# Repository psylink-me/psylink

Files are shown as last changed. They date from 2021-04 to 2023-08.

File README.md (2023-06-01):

# PsyLink






Open source [myoelectric](https://en.wikipedia.org/wiki/Electromyography) neural interface.

[Website](https://psylink.me) ::
[Documentation](https://codeberg.org/psylink/psylink/wiki) ::
[Matrix Chatroom](https://matrix.to/#/#psylink:matrix.org) ::
[FAQ](https://psylink.me/faq)

Photograph of PsyLink Prototype 10

# Introduction

**Psylink** is intended as a human input device (like a keyboard) that predicts your
intention from muscle signals.  Using a neural network, trained through a
process where you press keys at the exact same time that you make movements
with the limb wearing the device, it learns correlations between the muscle
signals and intended keys, and can press them for you.

- [Video demos @ PeerTube](https://peertube.linuxrocks.online/video-channels/psylink/videos)
- [Development Log](https://psylink.me/blog)
- [Whats Next?](https://codeberg.org/psylink/psylink/wiki/Next-Steps)

# Software used to create/edit/run these files

- Schematics, PCB Layouts: KiCad 6.0 (some archived ones used 5.1.5)
- Arduino IDE 1.8.19
    - ArduinoBLE 1.2.1
    - Arduino\_LSM9DS1 1.1.0
- Python 3.8
    - For library versions, see the respective requirements.txt file
- GnuRadio 3.8.1.0

# Datasheet

This describes [prototype 4](https://psylink.me/p4).

photo of the device

- Features:
    - Battery-powered
    - Wireless, using Bluetooth Low Energy (BLE)
    - Supports 17 electrodes (8 pairs + 1 ground)
    - Transmits 8 signals at 8-bit resolution, 500Hz sampling rate
    - Linux graphical user interface for:
        - Mapping keyboard key presses to muscle signals
        - Training a neural network to predict key presses from signals
        - Simulating key presses based on neural network predictions
    - GNURadio integration for plotting the raw signals + FFT
- Hardware overview:
    - A fabric glove/sleeve with a central component (arduino + power supply)
      and 8 distributed signal clean-up units close to individual electrodes.
    - [KiCad Schematic](schematics/myocular0.5.1.sch)
    - [KiCad PCB of one distributed signal clean-up unit](schematics/myocular0.5.1d.kicad_pcb)
- Software dependencies:
    - Python3 (see [requirements.txt](python/requirements.txt))
        - [BLE-GATT](https://pypi.org/project/BLE-GATT/)
        - [matplotlib](https://matplotlib.org/)
        - [pynput](https://pypi.org/project/pynput/)
        - [tensorflow](https://www.tensorflow.org/)
        - [Pillow](https://python-pillow.org)
        - possibly the `python3-pil.imagetk` package
    - ArduinoIDE
        - [ArduinoBLE](https://www.arduino.cc/en/Reference/ArduinoBLE)
        - [Arduino LSM9DS1](https://www.arduino.cc/en/Reference/ArduinoLSM9DS1) (for accelerometer/gyroscope)
- Components:
    - 1x [Arduino Nano 33 BLE Sense](https://store.arduino.cc/arduino-nano-33-ble-sense)
    - 1x [LM324 Operational Amplifier](https://www.ti.com/product/LM324)
    - 8x [INA128 Instrumentational Amplifier](https://www.ti.com/product/INA128)
    - Any portable 6V power supply (like 2x CR2032)
    - 17x Electrodes, e.g. [Prym 390120](https://www.prym.com/en/non-sew-refill-for-390120-smooth-cap-10mm-silver-coloured-390104) (don't laugh, they work)
    - A forearm sleeve from non-conductive fabric
    - Additional standard components (see schematic)
- Power ratings
    - Supply Voltage: 4.5-6V
    - Power dissipation:
        - Idle: ~86.9mW (16.9mA x 5.14V)
        - Transmitting at 6-7kB/s: 92.5mW (18.0mA x 5.14V)
- Weight: ~85g (at 9.81m/s² gravitational acceleration)

# Acknowledgements

Very special thanks to every contributor. You all shaped the direction of this
project in your unique way, and we would not be at this point without you!

- [Roman Zimbelmann](https://rzim.dev): Founder and maintainer of PsyLink
- [Alex Lao](http://www.voltagedivide.com/): Consulting
- [AntonX](https://www.linkedin.com/in/anton-x/): Consulting, hardware design
- [Cade Brown](https://cade.site/): Testing, financial support
- [Fabien Devaux](http://github.com/fdev31/): Consulting
- [Farzam Khodajoo](https://www.linkedin.com/in/farzam-khodajoo): Consulting, hardware design
- [Hackaday.com](https://hackaday.com/2022/01/07/psylink-an-open-source-neural-interface-for-non-invasive-emg/): Spreading the word, networking
- [John Shahbazian](https://github.com/jshahbazi): Consulting, testing, software, financial support
- keks: Consulting, testing
- knoc: Consulting, testing
- [ktrask](https://twitter.com/ktrask23) ([mastodon](https://chaos.social/@ktrask)): Consulting, testing
- [PCBWay](https://pcbway.com): Sponsored production services
- [PerlinWarp](https://twitter.com/perlinwarp): Consulting, testing, documentation, networking, financial support
- Ricard Collins: Consulting, financial support, testing
- [Wojciech Siewierski](https://einval.eu): Consulting
- Thanks to all the patrons on [Liberapay](https://liberapay.com/psylink/) for financial support!

# License

Copyright (C) 2023  Roman Zimbelmann

This program is free software: you can redistribute it and/or modify
it under the terms of the GNU General Public License version 3 as
published by the Free Software Foundation.

This program is distributed in the hope that it will be useful,
but WITHOUT ANY WARRANTY; without even the implied warranty of
MERCHANTABILITY or FITNESS FOR A PARTICULAR PURPOSE.  See the
GNU General Public License for more details.

You should have received a copy of the GNU General Public License
along with this program.  If not, see <https://www.gnu.org/licenses/>.

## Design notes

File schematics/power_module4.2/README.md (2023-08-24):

# PsyLink Power Module 4.2

This board connects to a [Arduino Nano 33 BLE](https://docs.arduino.cc/hardware/nano-33-ble) or [BLE Sense](https://docs.arduino.cc/hardware/nano-33-ble-sense) and a AAA battery, with the purpose to power the Arduino and expose a variety of I/O pins and power pins in order to power further boards such as the PsyLink electrode modules.

Though it was designed to drive PsyLink electrode modules, it can also be used stand-alone as a battery-powered break-out board for any Arduino board that is pin-compatible with the [Arduino Nano 33 BLE](https://docs.arduino.cc/hardware/nano-33-ble), for example as a mobile [water detector](https://psylink.me/blog/retro2022/#psylink-as-a-break-out-board):

Photograph of the PsyLink power module 4.2 with a speaker plugged in to D10/D13, and two wires on A0 and GND, above a cup of water. When both wires touch the water, the speaker makes some noise.

# Overview

- Part ID: ["bp4.2"](https://psylink.me/bp4.2/)
- Circuit ID: ["12.1"](https://psylink.me/c12.1/)
- Dimensions: 90 x 32.6mm
- Finalized on: 2022-01-26
- Tested: Yes
- Bill of materials: [LibreOffice .ods file](https://psylink.me/tables/bom_p10.ods)
- Known bugs:
    - Power LED (D1) drains a lot of power. Mitigate this by increasing the resistor (R5) or removing the LED entirely - there is another power LED on the Arduino anyway.

# Main Features

- Provides 5V operating voltage for the Arduino and the rest of the circuit by boosts the battery voltage up to 5V with a [TSP61220](https://www.ti.com/product/de-de/TPS61220) step-up converter
- Supports AAA batteries. Tested with 1.5V non-rechargeable, and 1.2V NiMH rechargeable. Plugged into "Keystone 82" battery clips
- Generates 2.5V Reference Voltage (Vref) with a [LM321](https://www.ti.com/product/LM321) for the ground electrode and to serve as a baseline for the electrode modules
- Exposes Arduino pins A0-A8, D2, D3, D10-D13
- Exposes power output connectors that supply V+, Vref, GND. Three sets of these are available to power 3 electrode modules, but more can be connected via daisy-chaining.
- Features an optional power LED, though I recommend leaving it out to conserve power. The Arduino already provides another power LED.
- Provides mounting points for 5 dome nuts (e.g. [M3 dome nuts of A2 stainless steel](https://www.schraubenking.at/M3-Hutmutter-DIN1587-Edelstahl-A2-P002263)) that act as ground electrode and spacers between the board and the skin, although it is still required to place insulating tape over any exposed metal on the board (other than the screws) to ensure proper function
- Can be worn on a limb by utilizing the rubber band holes on the sides of the PCB.
    -  An isolating tape must fully cover any metal contact points the bottom side
- Supports a 3.3V operating mode by changing the value of R2 from 110kΩ to 180kΩ. This will also change Vref from 2.5V to 1.65V, and if you use a power LED, its resistor R5 may need adjustment.
- You can change the values for R3, R4, and all capacitors by ~1 order of magnitude without too much impact. R3 needs to be equal to R4. R5 may need to be adapted to whichever LED and supply voltage you use, see e.g. [this LED resistor calculator](https://www.allaboutcircuits.com/tools/led-resistor-calculator/).
- Customization via jumpers:
    - JP1: Exposes D2, GND, D3, so you can ground D2 or D3 with a jumper to change the device behavior on the fly
    - JP2: Enable measuring the battery voltage with A7, which sacrifices one electrode signal
    - JP3: Solder jumper to enable the reference voltage generator
    - JP4-JP8: Enables one of the 5 screws/dome-nuts to act as a ground electrode. At least one of them should be activated, and the screw should touch the skin.

# IMPORTANT ASSEMBLY INSTRUCTIONS

- Cover the bottom of the board with isolating tape if it is placed on the skin
- The inductance L1 must be rated for at least 230mA
- Before soldering on any through-hole components, their pins must be shortened with e.g. wire cutters so that they do not extend out of the board on the bottom side, to avoid scratching the skin
- You must close the solder jumpers JP3 and (e.g.) JP4 for proper function
- The screws connect Vref to the skin (if their resp. jumper is closed). You MUST manually connect Vref with the skin if this board is not worn on the skin directly and if you use this board along with the electrode modules for EMG purposes. Keep a distance of at least 3cm with this ground electrode from any other electrode.
- It's more comfortable to wear if you leave out screw 5.

# PCB Images

Front Side

Back Side

# Circuit Image

Circuit

# Changelog

Power Module 4.2:

- Added logo
- Added "OFF" and "ON" labels to power switch
- Simplified power LED circuit: it is now always connected to V+ instead of giving you the choice between V+ and Vref via a jumper
- Moved the external power pins (J7) away from the center of the battery, so the pin headers are not physically in the way when removing the battery.

Power Module 4.1:

- Added pins for external power supply
- Added optional power LED circuit, with a jumper (JP9) that lets you choose between powering it with Vref (should consume less power) or V+ (in case you disable Vref generator via jumper JP3)
- Repositioned some parts

Power Module 4.0:

- Redesigned from scratch to be worn on the arm directly, instead of being attached to a piece of fabric via velcro as before
- Longer but thinner board by repositioning the battery in line with the Arduino rather than side-by-side, so that it fits better on the arm
- Added holes for rubber bands on the sides, compatible with corresponding electrode modules.
- Added screw mounting slots for ground electrodes, connected to Vref. Only one of them needs to be enabled via a jumper (JP4-JP8)
- Power output pins (V+, Vref, GND) for powering electrode modules are now separated from the I/O pins into distinct 3-pin connectors
- Added a third set of power output pins
- New dimensions: 90 x 32.6mm

Power Module 3.1:

- Changed package for L1 inductance coil from 1206 to 1210, so one can fit larger coils with a higher maximum current rating on it
- For easier soldering, added thermal reliefs on the filled area for GND on the back side
- For easier soldering, added larger pads for L1/U*/R*/C* components (see [issue #8](https://codeberg.org/psylink/psylink/issues/8))
- No changes to the circuit

Power Module 3:

- Redesigned PCB from scratch
- Actually works
- Both Arduino and battery clips are now on the top side
- Added bypass capacitors to reduce noise
- Added various jumpers:
    - A solder jumper to enable/disable the reference voltage generator, to save power when it's not needed
    - A solder jumper to sacrifice one electrode and use its analog input pin to measure the battery charge instead.
    - Three configuration pins that expose the Arduino's D2, GND, D3 pins, connectable via jumpers, to change software settings on the fly and toggle between up to 4 different modes. Or you can use them to plug in an extra module.
- New dimensions: 47.63 x 31.34mm

Power Module 2 (defunct):

- Switched from manual wiring to PCB
- Switched from 2x 1.5V coin cells to single 1.2V AAA rechargeable battery
- The battery clips are mounted on the front side whereas the Arduino is mounted on the back side. (this makes it more compact, but unfortunately hard to wear)
- Added boost converter ([TPS61220](https://www.ti.com/product/de-de/TPS61220)) to generate 5V
- Switched from thru-hole LM324 to SMD [LM321](https://www.ti.com/product/LM321) for reference voltage generation
- Outputs 2x 5V, 2x GND, 2x Vref (2.5V) - theoretically. I never got it to work.
- New dimensions: 50 x 25mm

Power Module 1:

- Initial version
- Manual wiring on a prototyping board
- Generating reference voltage with a LM324 chip
- Using 2x 1.5V CR2032 coin cells
- Outputs 2x 3V, 2x GND, 1x Vref (1.5V)
- Dimensions: 36 x 30mm

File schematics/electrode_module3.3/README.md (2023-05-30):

# PsyLink Electrode Module 3.3

- Part ID: ["b3.2"](https://psylink.me/b3.2/)
- Circuit ID: ["10.3"](https://psylink.me/c10.3/)
- Dimensions: 70 x 25mm
- Finalized on: 2023-05-31
- Tested: Yes
- Known bugs:
    - Excessive interference along "out2" trace.

# PCB Images

Front Side

Back Side

# Circuit Image

Circuit

# Changelog
## Circuit

Electrode Module 3.3:

- Fixed aggressive filtering of signals by changing passive highpass filter capacitors C1-C8 from 100pF to 100nF.

Electrode Module 3.2:

- Gain resistors R9, R11, R12 have been reduced from 1000 Ohms to 100 Ohms, raising the gain tenfold, from 51x to 501x.
- Gain resistor R10 was only reduced to 200 Ohms, raising the gain to only 251x. This was done to offset an interference bug along the out2 trace.  Once this is fixed, the resistance should be set to equal that of R9/R11/R12 once again.
- JP1-JP8 are now closed by default, to save time during assembly

## PCB

Electrode Module 3.3:

- No changes.

Electrode Module 3.2:

- Moved EX1 closer to EX5 and EX4 closer to EX8, so that two 2-pin-headers can be used instead of four 1-pin headers
- Longer solder pads on U1-U4 for easier hand-soldering
- Improved labels, added PsyLink logo

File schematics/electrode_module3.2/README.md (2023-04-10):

# PsyLink Electrode Module 3.2

- Part ID: ["b3.2"](https://psylink.me/b3.2/)
- Circuit ID: ["10.2"](https://psylink.me/c10.2/)
- Dimensions: 70 x 25mm
- Finalized on: 2022-01-26
- Tested: Yes
- Known bugs:
    - Excessive interference along "out2" trace.
    - Too aggressive filtering through 100pF (C1-C8) capacitors. Solved by changing them to 100nF.

# PCB Images

Front Side

Back Side

# Circuit Image

Circuit

# Changelog
## Circuit

Electrode Module 3.2:

- Gain resistors R9, R11, R12 have been reduced from 1000 Ohms to 100 Ohms, raising the gain tenfold, from 51x to 501x.
- Gain resistor R10 was only reduced to 200 Ohms, raising the gain to only 251x. This was done to offset an interference bug along the out2 trace.  Once this is fixed, the resistance should be set to equal that of R9/R11/R12 once again.
- JP1-JP8 are now closed by default, to save time during assembly

## PCB

Electrode Module 3.2:

- Moved EX1 closer to EX5 and EX4 closer to EX8, so that two 2-pin-headers can be used instead of four 1-pin headers
- Longer solder pads on U1-U4 for easier hand-soldering
- Improved labels, added PsyLink logo

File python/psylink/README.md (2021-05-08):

A python library for interfacing with the PsyLink device

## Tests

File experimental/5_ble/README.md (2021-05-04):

This consists of multiple parts.

# GNURadio

- Dependencies:
    - `BLE_GANTT` python library

# Stand-alone scripts

These are mostly for testing/debugging.  I tried out different python BLE
libraries which have their individual dependencies.  You'll figure it out.

# Arduino

- RGB LED color codes:
    - Red LED: Bluetooth Low Energy failed to initialize
    - Yellow LED: Timer failed to initialize
    - Blue LED: Bluetooth device is connected
    - No LED: Everything went well, but no device is connected yet
- Dependencies:
    - `ArduinoBLE` library
    - [`NRF52_MBED_TimerInterrupt`](https://github.com/khoih-prog/NRF52_MBED_TimerInterrupt) library

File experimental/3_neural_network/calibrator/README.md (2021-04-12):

Setup instructions:

Don't.  I don't think you really want to use it, it's not really polished,
because I just build it for myself.  If this warning doesn't stop you, here are
some instructions:

1. Install Linux, Python3(.8), "xdotool"
2. Download code
3. Build a python virtual env based on the requirements.txt and activate it
4. Adjust constants in the code, like
    - Path to serial port of the microcontroller
5. From inside a terminal, run ./run.py

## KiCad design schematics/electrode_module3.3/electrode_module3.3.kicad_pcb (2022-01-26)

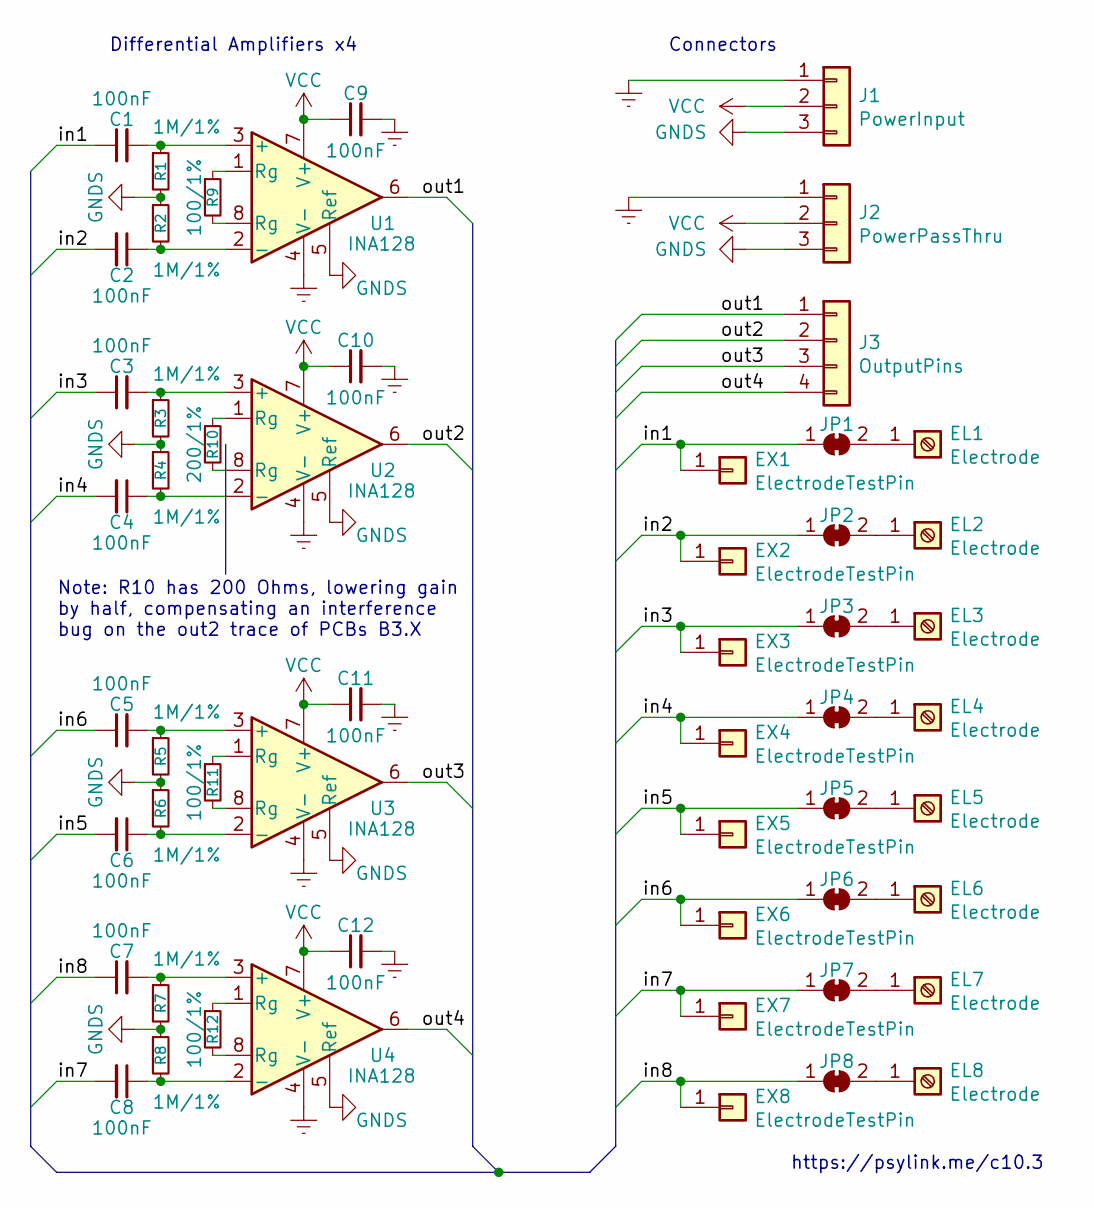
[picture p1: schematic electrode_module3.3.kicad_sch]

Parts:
C1, C2, C3, C4, C5, C6, C7, C8, C9, C10, C11, C12: 100nF; C_0805_2012Metric_Pad1.15x1.40mm_HandSolder
EL1, EL2, EL3, EL4, EL5, EL6, EL7, EL8: Electrode; MountingHole_3.7mm_Pad
EX1, EX2, EX3, EX4, EX5, EX6, EX7, EX8: ElectrodeTestPin; PinHeader_1x01_P2.54mm_Vertical
J1: PowerInput; PinHeader_1x03_P2.54mm_Vertical
J2: PowerPassThru; PinHeader_1x03_P2.54mm_Vertical
J3: OutputPins; PinHeader_1x04_P2.54mm_Vertical
JP1, JP2, JP3, JP4, JP5, JP6, JP7, JP8: SolderJumper_2_Bridged; SolderJumper-2_P1.3mm_Bridged_RoundedPad1.0x1.5mm
R1, R2, R3, R4, R5, R6, R7, R8: 1M/1%; R_0805_2012Metric_Pad1.15x1.40mm_HandSolder
R9, R11, R12: 100/1%; R_0805_2012Metric_Pad1.15x1.40mm_HandSolder
R10: 200/1%; R_0805_2012Metric_Pad1.15x1.40mm_HandSolder
U1, U2, U3, U4: INA128; SOIC-8_3.9x4.9mm_P1.27mm

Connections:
/in1: C1.1, EX1.1, JP1.1 (A)
/in2: C2.2, EX2.1, JP2.1 (A)
/in3: C3.1, EX3.1, JP3.1 (A)
/in4: C4.2, EX4.1, JP4.1 (A)
/in5: C6.2, EX5.1, JP5.1 (A)
/in6: C5.1, EX6.1, JP6.1 (A)
/in7: C8.2, EX7.1, JP7.1 (A)
/in8: C7.1, EX8.1, JP8.1 (A)
/out1: J3.1, U1.6
/out2: J3.2, U2.6
/out3: J3.3, U3.6
/out4: J3.4, U4.6
Earth: C9.2, C10.2, C11.2, C12.2, J1.1, J2.1, U1.4 (V-), U2.4 (V-), U3.4 (V-), U4.4 (V-)
GNDS: J1.3, J2.3, R1.2, R2.1, R3.2, R4.1, R5.2, R6.1, R7.2, R8.1, U1.5 (Ref), U2.5 (Ref), U3.5 (Ref), U4.5 (Ref)
unnamed: C1.2, R1.1, U1.3 (+)
unnamed: C2.1, R2.2, U1.2 (-)
unnamed: C3.2, R3.1, U2.3 (+)
unnamed: C4.1, R4.2, U2.2 (-)
unnamed: C5.2, R5.1, U3.3 (+)
unnamed: C6.1, R6.2, U3.2 (-)
unnamed: C7.2, R7.1, U4.3 (+)
unnamed: C8.1, R8.2, U4.2 (-)
unnamed: EL1.1, JP1.2 (B)
unnamed: EL2.1, JP2.2 (B)
unnamed: EL3.1, JP3.2 (B)
unnamed: EL4.1, JP4.2 (B)
unnamed: EL5.1, JP5.2 (B)
unnamed: EL6.1, JP6.2 (B)
unnamed: EL7.1, JP7.2 (B)
unnamed: EL8.1, JP8.2 (B)
unnamed: R9.1, U1.1 (Rg)
unnamed: R9.2, U1.8 (Rg)
unnamed: R10.1, U2.1 (Rg)
unnamed: R10.2, U2.8 (Rg)
unnamed: R11.1, U3.1 (Rg)
unnamed: R11.2, U3.8 (Rg)
unnamed: R12.1, U4.1 (Rg)
unnamed: R12.2, U4.8 (Rg)
VCC: C9.1, C10.1, C11.1, C12.1, J1.2, J2.2, U1.7 (V+), U2.7 (V+), U3.7 (V+), U4.7 (V+)

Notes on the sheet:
Note: R10 has 200 Ohms, lowering gain by half, compensating an interference bug on the out2 trace of PCBs B3.X
https://psylink.me/c10.3
Differential Amplifiers x4
Connectors

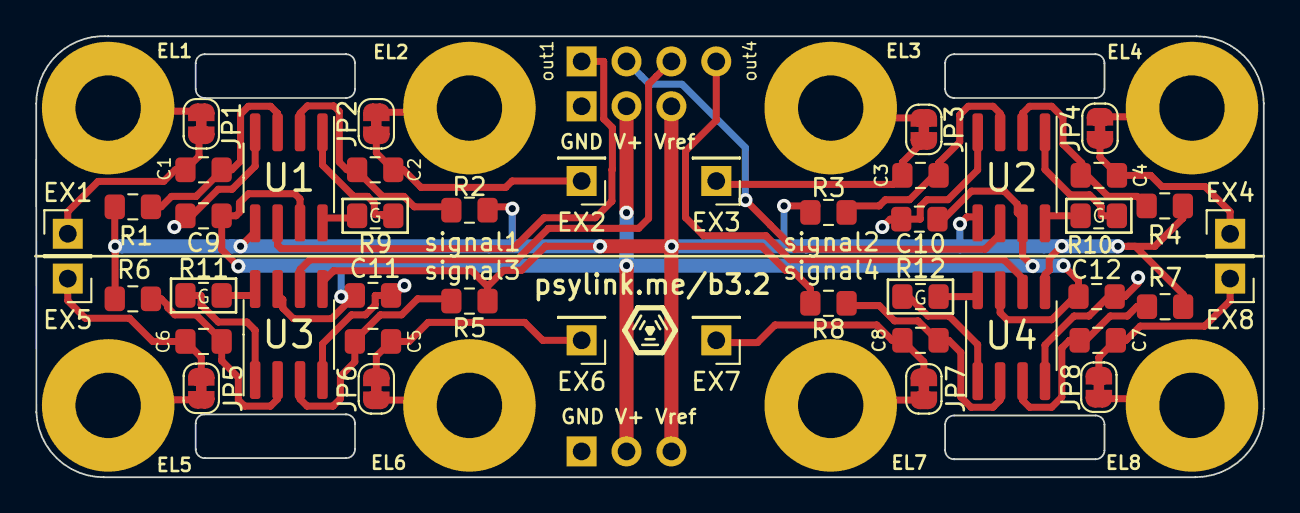
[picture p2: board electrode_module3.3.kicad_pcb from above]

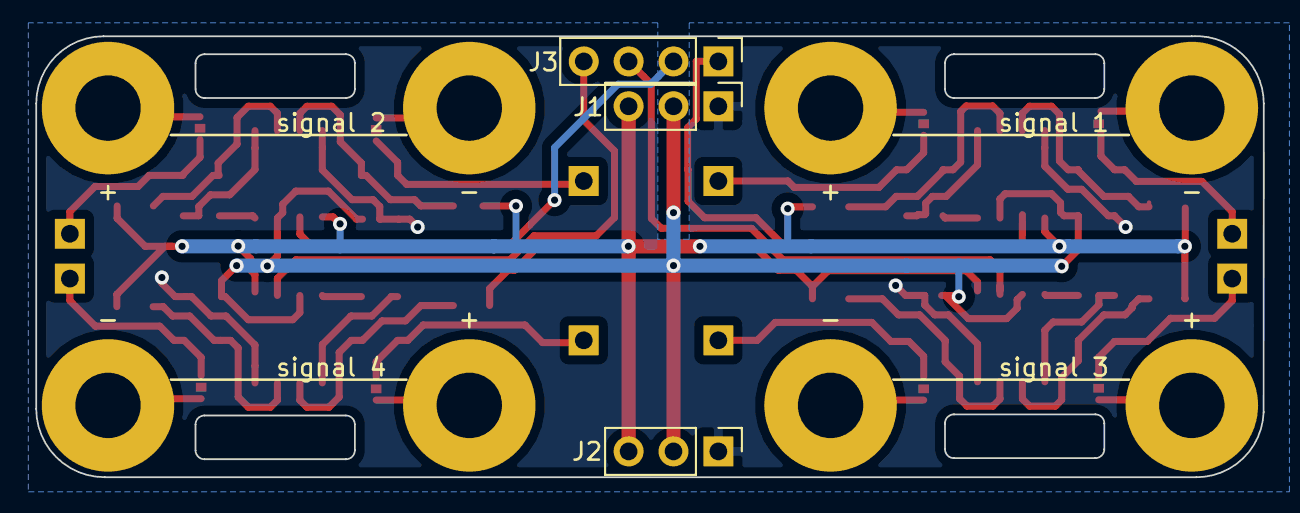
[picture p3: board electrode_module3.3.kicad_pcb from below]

Board: 2 copper layers, 69.5 x 25.0 mm, 55 parts (3 on the bottom side), 39 nets.

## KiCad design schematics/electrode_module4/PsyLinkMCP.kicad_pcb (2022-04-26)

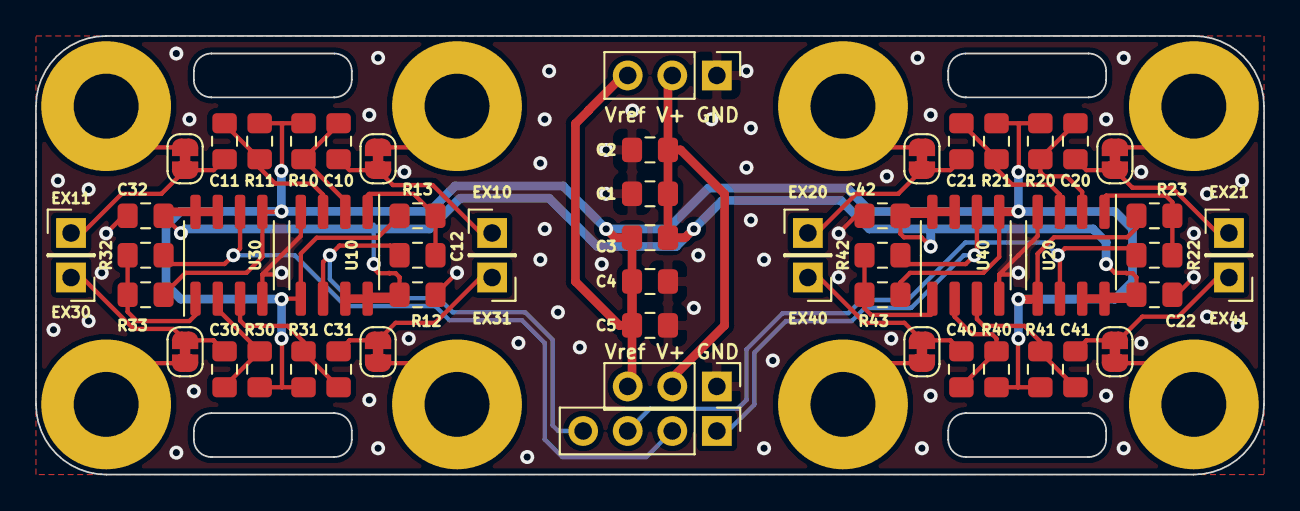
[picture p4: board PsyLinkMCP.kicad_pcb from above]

Board: 2 copper layers, 70.0 x 25.0 mm, 64 parts (0 on the bottom side), 34 nets.

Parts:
C1, C3, C4, C12, C22, C32, C42: 100nF; C_0805_2012Metric_Pad1.15x1.40mm_HandSolder
C2, C5: 10uF; C_0805_2012Metric_Pad1.15x1.40mm_HandSolder
C10, C11, C20, C21, C30, C31, C40, C41: 100pF; C_0805_2012Metric_Pad1.15x1.40mm_HandSolder
EL10, EL11, EL20, EL21, EL30, EL31, EL40, EL41: Electrode; MountingHole_3.7mm_Pad
EX10, EX11, EX20, EX21, EX30, EX31, EX40, EX41: ElectrodeTestPin; PinHeader_1x01_P2.54mm_Vertical
J1: PowerInput; PinHeader_1x03_P2.54mm_Vertical
J2: PowerPassThru; PinHeader_1x03_P2.54mm_Vertical
J3: OutputPins; PinHeader_1x04_P2.54mm_Vertical
JP10, JP11, JP20, JP21, JP30, JP31, JP40, JP41: SolderJumper_2_Bridged; SolderJumper-2_P1.3mm_Bridged_RoundedPad1.0x1.5mm
R10, R11, R20, R21, R30, R31, R40, R41: 1M/1%; R_0805_2012Metric_Pad1.15x1.40mm_HandSolder
R12, R22, R32, R42: 100k/1%; R_0805_2012Metric_Pad1.15x1.40mm_HandSolder
R13, R33, R43: 200/1%; R_0805_2012Metric_Pad1.15x1.40mm_HandSolder
R23: 400/1%; R_0805_2012Metric_Pad1.15x1.40mm_HandSolder
U10, U20, U30, U40: MCP6N11; SOIC-8_3.9x4.9mm_P1.27mm

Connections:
/in10: C10.1, EX10.1, JP10.1
/in11: C11.2, EX11.1, JP11.1
/in20: C20.1, EX21.1, JP20.1
/in21: C21.2, EX20.1, JP21.1
/in30: C30.1, EX30.1, JP30.1
/in31: C31.2, EX31.1, JP31.1
/in40: C40.1, EX40.1, JP40.1
/in41: C41.2, EX41.1, JP41.1
/out1: J3.4, R12.2, U10.6
/out2: J3.3, R22.2, U20.6
/out3: J3.2, R32.2, U30.6
/out4: J3.1, R42.2, U40.6
GND: C1.1, C2.1, C4.1, C5.1, C12.2, C22.2, C32.2, C42.2, J1.1, J2.1, U10.4, U20.4, U30.4, U40.4
unnamed: C10.2, R10.1, U10.2
unnamed: C11.1, R11.2, U10.3
unnamed: C20.2, R20.1, U20.2
unnamed: C21.1, R21.2, U20.3
unnamed: C30.2, R30.1, U30.2
unnamed: C31.1, R31.2, U30.3
unnamed: C40.2, R40.1, U40.2
unnamed: C41.1, R41.2, U40.3
unnamed: EL10.1, JP10.2
unnamed: EL11.1, JP11.2
unnamed: EL20.1, JP20.2
unnamed: EL30.1, JP30.2
unnamed: EL31.1, JP31.2
unnamed: EL40.1, JP40.2
unnamed: EL41.1, JP41.2
unnamed: R12.1, R13.1, U10.1
unnamed: R22.1, R23.1, U20.1
unnamed: R32.1, R33.1, U30.1
unnamed: R42.1, R43.1, U40.1
REF: C3.1, C4.2, C5.2, J1.3, J2.3, R10.2, R11.1, R13.2, R20.2, R21.1, R23.2, R30.2, R31.1, R33.2, R40.2, R41.1, R43.2, U10.5, U20.5, U30.5, U40.5
VCC: C1.2, C2.2, C3.2, C12.1, C22.1, C32.1, C42.1, J1.2, J2.2, U10.7, U10.8, U20.7, U20.8, U30.7, U30.8, U40.7, U40.8

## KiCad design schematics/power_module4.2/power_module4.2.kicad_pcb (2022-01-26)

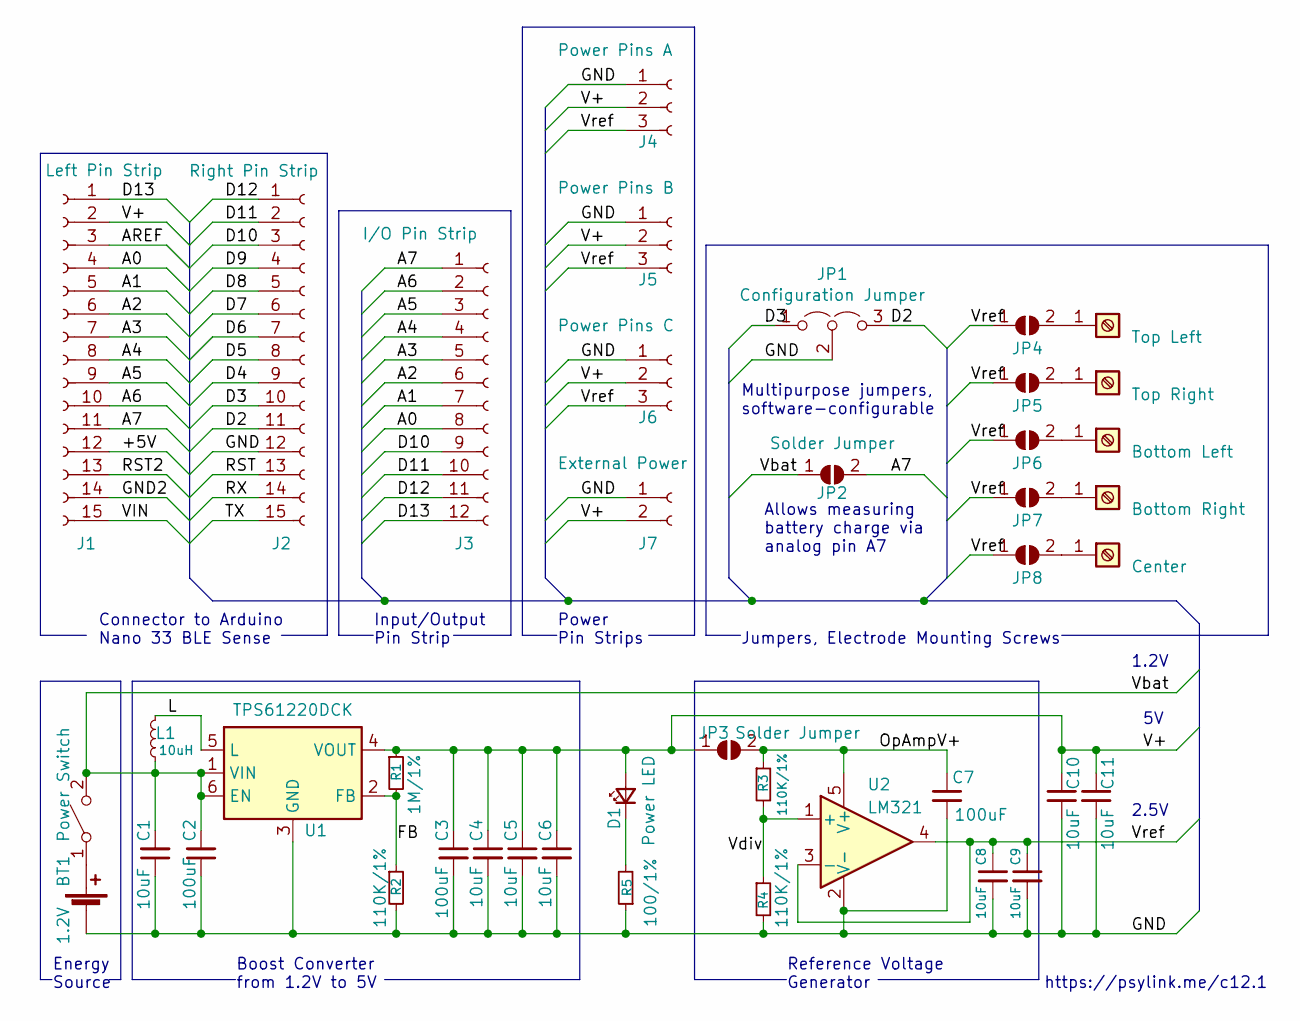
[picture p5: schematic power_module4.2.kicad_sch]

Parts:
BT1: 1.2V; BatteryHolder_Keystone_82_1xAAA
C1, C4, C5, C6, C8, C9, C10, C11: 10uF; C_1206_3216Metric_Pad1.42x1.75mm_HandSolder
C2, C3, C7: 100uF; C_1206_3216Metric_Pad1.42x1.75mm_HandSolder
D1: Power LED; LED_0805_2012Metric_Pad1.15x1.40mm_HandSolder
J1: Left Pin Strip; PinSocket_1x15_P2.54mm_Vertical
J2: Right Pin Strip; PinSocket_1x15_P2.54mm_Vertical
J3: I/O Pin Strip; PinHeader_1x12_P2.54mm_Vertical
J4: Power Pins A; PinHeader_1x03_P2.54mm_Vertical
J5: Power Pins B; PinHeader_1x03_P2.54mm_Vertical
J6: Power Pins C; PinHeader_1x03_P2.54mm_Vertical
J7: External Power; PinHeader_1x02_P2.54mm_Vertical
JP1: Configuration Jumper; PinSocket_1x03_P2.54mm_Vertical
JP2, JP3: Solder Jumper; SolderJumper-2_P1.3mm_Open_RoundedPad1.0x1.5mm
JP4, JP5, JP6, JP7, JP8: SolderJumper_2_Open; SolderJumper-2_P1.3mm_Open_RoundedPad1.0x1.5mm
L1: 10uH; L_1210_3225Metric_Pad1.42x2.65mm_HandSolder
R1: 1M/1%; R_0805_2012Metric_Pad1.15x1.40mm_HandSolder
R2, R3, R4: 110K/1%; R_0805_2012Metric_Pad1.15x1.40mm_HandSolder
R5: 100/1%; R_0805_2012Metric_Pad1.15x1.40mm_HandSolder
SW1: Power Switch; PinSocket_1x03_P2.54mm_Vertical
U1: TPS61220DCK; Texas_R-PDSO-G6
U2: LM321; SOT-23-5

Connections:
/+5V: J1.12
/A0: J1.4, J3.8
/A1: J1.5, J3.7
/A2: J1.6, J3.6
/A3: J1.7, J3.5
/A4: J1.8, J3.4
/A5: J1.9, J3.3
/A6: J1.10, J3.2
/A7: J1.11, J3.1, JP2.2 (B)
/AREF: J1.3
/D2: J2.11, JP1.3 (B)
/D3: J2.10, JP1.1 (A)
/D4: J2.9
/D5: J2.8
/D6: J2.7
/D7: J2.6
/D8: J2.5
/D9: J2.4
/D10: J2.3, J3.9
/D11: J2.2, J3.10
/D12: J2.1, J3.11
/D13: J1.1, J3.12
/FB: R1.2, R2.1, U1.2 (FB)
/GND: BT1.2 (-), C1.1, C2.1, C3.2, C4.2, C5.2, C6.2, C7.2, C8.2, C9.2, C10.2, C11.2, J2.12, J4.1, J5.1, J6.1, J7.1, JP1.2 (C), R2.2, R4.2, R5.1, U1.3 (GND), U2.2 (V-)
/GND2: J1.14
/L: L1.2, U1.5 (L)
/OpAmpV+: C7.1, JP3.2 (B), R3.1, U2.5 (V+)
/RST: J2.13
/RST2: J1.13
/RX: J2.14
/TX: J2.15
/V+: C3.1, C4.1, C5.1, C6.1, C10.1, C11.1, D1.2 (A), J1.2, J4.2, J5.2, J6.2, J7.2, JP3.1 (A), R1.1, U1.4 (VOUT)
/VIN: J1.15
/Vbat: C1.2, C2.2, JP2.1 (A), L1.1, SW1.2 (B), U1.1 (VIN), U1.6 (EN)
/Vdiv: R3.2, R4.1, U2.1 (+)
/Vref: C8.1, C9.1, J4.3, J5.3, J6.3, JP4.1 (A), JP5.1 (A), JP6.1 (A), JP7.1 (A), JP8.1 (A), U2.3 (-), U2.4
unnamed: BT1.1 (+), SW1.1 (A)
unnamed: D1.1 (K), R5.2
unnamed 38: JP4.2 (B); also elsewhere on the board
unnamed 39: JP5.2 (B); also elsewhere on the board
unnamed 40: JP6.2 (B); also elsewhere on the board
unnamed 41: JP7.2 (B); also elsewhere on the board
unnamed 42: JP8.2 (B); also elsewhere on the board

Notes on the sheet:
https://psylink.me/c12.1
Jumpers, Electrode Mounting Screws
Allows measuring battery charge via analog pin A7
2.5V
Reference Voltage Generator
Energy Source
1.2V
Connector to Arduino Nano 33 BLE Sense
Boost Converter from 1.2V to 5V
Multipurpose jumpers, software-configurable
Input/Output Pin Strip
Power Pin Strips

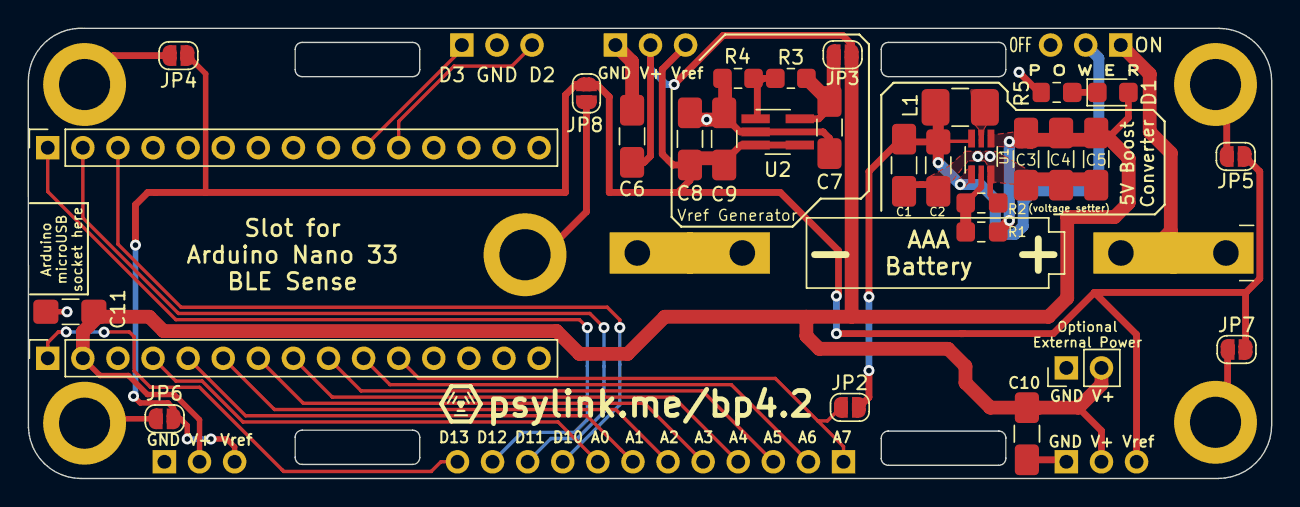
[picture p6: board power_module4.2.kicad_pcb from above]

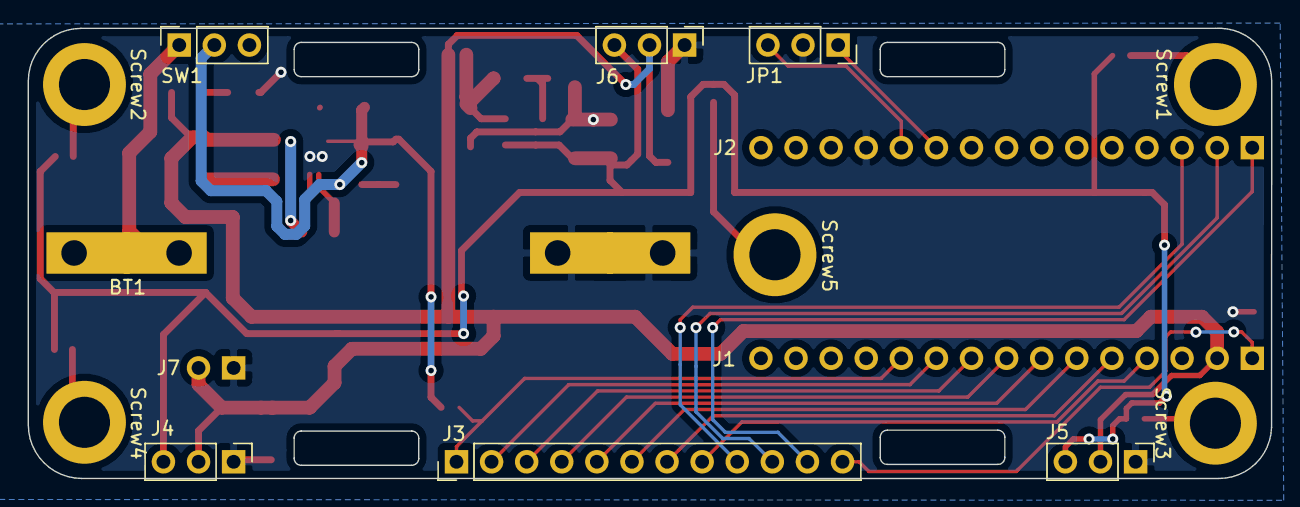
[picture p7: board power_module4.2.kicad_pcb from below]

Board: 2 copper layers, 90.0 x 32.6 mm, 42 parts (6 on the bottom side), 29 nets.

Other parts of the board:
Screw1: Top Left; MountingHole_3.7mm_Pad
Screw2: Top Right; MountingHole_3.7mm_Pad
Screw3: Bottom Left; MountingHole_3.7mm_Pad
Screw4: Bottom Right; MountingHole_3.7mm_Pad
Screw5: Center; MountingHole_3.7mm_Pad

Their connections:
unnamed 38: Screw1.1; also elsewhere on the board
unnamed 39: Screw2.1; also elsewhere on the board
unnamed 40: Screw3.1; also elsewhere on the board
unnamed 41: Screw4.1; also elsewhere on the board
unnamed 42: Screw5.1; also elsewhere on the board

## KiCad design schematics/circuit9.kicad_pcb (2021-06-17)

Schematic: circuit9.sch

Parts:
BT1: 1.2V; BatteryHolder_Keystone_82_1xAAA
C1, C2, C3, C4, C5, C6, C7, C8, C9, C10, C11: 100uF; C_1206_3216Metric
J1: Left Pin Strip; PinSocket_1x15_P2.54mm_Vertical
J2: Right Pin Strip; PinSocket_1x15_P2.54mm_Vertical
J3: I/O Pin Strip; PinHeader_1x17_P2.54mm_Horizontal
JP1: Configuration Jumper; PinSocket_1x03_P2.54mm_Vertical
JP2, JP3: Solder Jumper; SolderJumper-2_P1.3mm_Open_RoundedPad1.0x1.5mm
L1: 4.7uH; L_1206_3216Metric_Pad1.42x1.75mm_HandSolder
R1, R3, R4: 1M/1%; R_0805_2012Metric
R2: 110K/1%; R_0805_2012Metric
SW1: Power Switch; PinSocket_1x03_P2.54mm_Vertical
U1: TPS61220DCK; Texas_R-PDSO-G6
U2: LM321; SOT-23-5

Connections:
/+5V: J1.12
/A0: J1.4, J3.14
/A1: J1.5, J3.13
/A2: J1.6, J3.12
/A3: J1.7, J3.11
/A4: J1.8, J3.10
/A5: J1.9, J3.9
/A6: J1.10, J3.8
/A7: J1.11, J3.7, JP2.2 (B)
/AREF: J1.3
/D2: J2.11, JP1.3 (B)
/D3: J2.10, JP1.1 (A)
/D4: J2.9
/D5: J2.8
/D6: J2.7
/D7: J2.6
/D8: J2.5
/D9: J2.4
/D11: J2.2, J3.15
/D12: J2.1, J3.16
/D13: J1.1, J3.17
/FB: R1.2, R2.1, U1.2 (FB)
/GND: BT1.2 (-), C1.1, C2.1, C3.2, C4.2, C5.2, C6.2, C7.2, C8.2, C9.2, C10.2, C11.2, J2.12, J3.1, J3.2, JP1.2 (C), R2.2, R4.2, U1.3 (GND), U2.2 (V-)
/GND2: J1.14
/L: L1.2, U1.5 (L)
/OpAmpV+: C7.1, JP3.2 (B), R3.1, U2.5 (V+)
/RST: J2.13
/RST2: J1.13
/RX: J2.14
/TX: J2.15
/V+: C3.1, C4.1, C5.1, C6.1, C10.1, C11.1, J1.2, J3.3, J3.4, JP3.1 (A), R1.1, U1.4 (VOUT)
/VIN: J1.15
/Vbat: C1.2, C2.2, J2.3, JP2.1 (A), L1.1, SW1.2 (B), U1.1 (VIN), U1.6 (EN)
/Vdiv: R3.2, R4.1, U2.1 (+)
/Vref: C8.1, C9.1, J3.5, J3.6, U2.3 (-), U2.4
unnamed: BT1.1 (+), SW1.1 (A)

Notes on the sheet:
2.5V
1.2V
Boost Converter from 1.2V to 5V
Reference Voltage Generator
Energy Source
Connector to Arduino Nano 33 BLE Sense
Allows measuring battery charge via analog pin A7
Input/Output Pin Strip
Multipurpose jumpers, software-configurable
Jumpers
https://psylink.me/c9

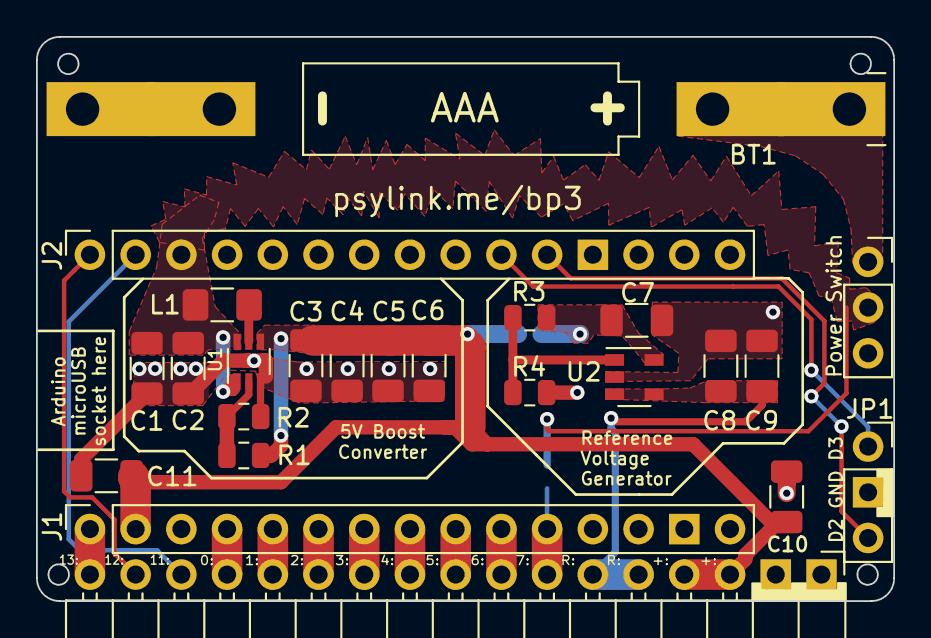
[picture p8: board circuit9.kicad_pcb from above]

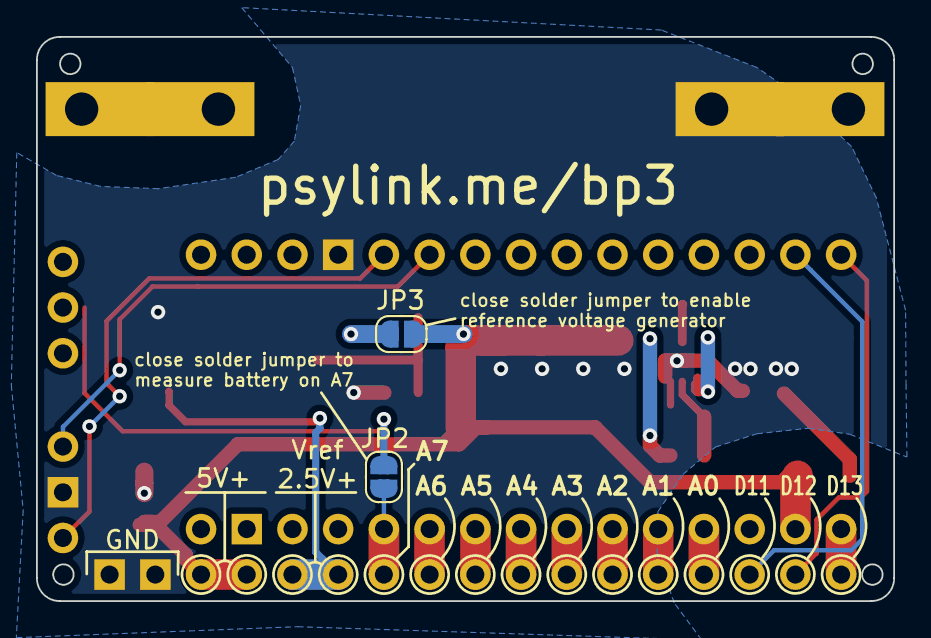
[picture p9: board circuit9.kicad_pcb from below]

Board: 2 copper layers, 47.6 x 31.3 mm, 26 parts (2 on the bottom side), 22 nets.

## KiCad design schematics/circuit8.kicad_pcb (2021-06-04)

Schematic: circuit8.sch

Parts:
BT1: 1.2V; BatteryHolder_Keystone_82_1xAAA
C1, C2, C3: 10uF; C_1206_3216Metric
J1: Arduino Left Pin Strip; PinSocket_1x15_P2.54mm_Vertical
J2: Arduino Right Pin Strip; PinSocket_1x15_P2.54mm_Vertical
J3: Output Pin Strip; PinSocket_1x17_P2.54mm_Vertical
L1: 4.7uH; L_0805_2012Metric
R1, R3, R4: 1M/1%; R_0805_2012Metric
R2: 110K/1%; R_0805_2012Metric
SW1: SW_DPST_x2; PinSocket_1x03_P2.54mm_Vertical
U1: TPS61220DCK; Texas_R-PDSO-G6
U2: LM321; SOT-23-5

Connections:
/A0: J1.4, J3.17
/A1: J1.5, J3.16
/A2: J1.6, J3.15
/A3: J1.7, J3.14
/A4: J1.8, J3.13
/A5: J1.9, J3.12
/A6: J1.10, J3.11
/A7: J1.11, J3.10
/D2: J2.11, J3.9
/D3: J2.10, J3.8
/D4: J2.9, J3.7
/D5: J2.8
/D6: J2.7
/GND: BT1.2 (-), C1.1, C2.2, C3.2, J1.14, J3.1, J3.2, R2.2, R4.2, U1.3 (GND), U2.2 (V-)
/V+: C2.1, J1.2, J3.3, J3.4, R1.1, R3.1, U1.4 (VOUT), U2.5 (V+)
/Vref: C3.1, J3.5, J3.6, U2.3 (-), U2.4
unnamed: BT1.1 (+), SW1.1 (A)
unnamed: C1.2, L1.1, SW1.2 (B), U1.1 (VIN), U1.6 (EN)
unnamed: L1.2, U1.5 (L)
unnamed: R1.2, R2.1, U1.2 (FB)
unnamed: R3.2, R4.1, U2.1 (+)

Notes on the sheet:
Power supply module
https://psylink.me/c8

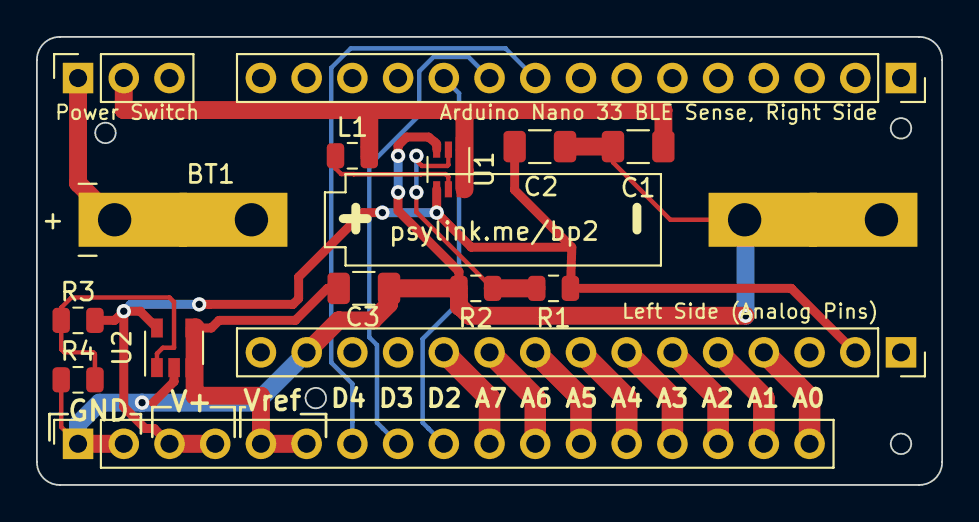
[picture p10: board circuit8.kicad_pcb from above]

Board: 2 copper layers, 50.3 x 24.9 mm, 15 parts (0 on the bottom side), 19 nets.

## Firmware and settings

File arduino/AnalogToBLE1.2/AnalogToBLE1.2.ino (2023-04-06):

// Dependencies: (Install in ArduinoIDE by clicking on Tools -> Manage Libraries...)
// 1. ArduinoBLE
// 2. Arduino_LSM9DS1

// Feature flags
#define SEND_METRICS true
#define USE_INTERRUPT_TIMER false

#include <ArduinoBLE.h>       // Bluetooth Low Energy
#include <Arduino_LSM9DS1.h>  // Inertial Measurement Unit
#if USE_INTERRUPT_TIMER == true
#include "NRF52_MBED_TimerInterrupt.h"
#endif

// Configuration
#define SAMPLE_RATE 500 // samples per second
#define BLE_NOTIFY_RATE 20 // updates per second
#define BLE_CONNECTION_INTERVAL_MIN 8 // in steps of 1.25ms
#define BLE_CONNECTION_INTERVAL_MAX 8 // in steps of 1.25ms
#define JUMPER_PIN_TO_DISABLE_IMU D2
#define CHANNELS 8
#define BUFFERS 2 // multiple buffers help with concurrency issues, if needed
#define METADATA_BYTES 8
// Metadata format:
// Bytes   |1   |2                            |3-5             |6-8                 |
// Bits    |all |1-4           |5-8           |all             |all                 |
// Content |Tick|MinSampleDelay|MaxSampleDelay|Gryoscope(x,y,z)|Accelerometer(x,y,z)|
// NOTE: MinSampleDelay and MaxSampleDelay will be 0xF when SEND_METRICS is false.

// The DELAY_PARAMs are from a logarithmic regression (f(x)=A+B*log(x)) with
// f(1000)=2 and f(500000)=14, so we can map ranges from <1000us to >500000us to 4 bits.
// Keep this in sync with python/psylink/protocol.py.
#define DELAY_PARAM_A -11.3384217
#define DELAY_PARAM_B 1.93093431
#define COMPRESS_DELAY(x) ((int) min(15, max(1, round(DELAY_PARAM_A + DELAY_PARAM_B * log(x)))))

// Constants
const int SAMPLE_INTERVAL_uS = 1000000 / SAMPLE_RATE;
const int BLE_NOTIFY_INTERVAL_MS = 1000 / BLE_NOTIFY_RATE;
const int SAMPLES_PER_NOTIFY = SAMPLE_RATE / BLE_NOTIFY_RATE;
// Ensure that BLE_CHARACTERISTICS_SIZE does not exceed BLE characteristic length limit of 512 bytes
const int BLE_CHARACTERISTIC_SIZE = METADATA_BYTES + CHANNELS * SAMPLES_PER_NOTIFY;
const int NO_BUFFER = -1;

#if USE_INTERRUPT_TIMER == true
NRF52_MBED_Timer samplingTimer(NRF_TIMER_3);
#endif
BLEDevice connectedDevice;
BLEService sensorService("0a3d3fd8-2f1c-46fd-bf46-eaef2fda91e4");
BLEStringCharacteristic sensorCharacteristic("0a3d3fd8-2f1c-46fd-bf46-eaef2fda91e5", BLERead, BLE_CHARACTERISTIC_SIZE);
BLEIntCharacteristic channelCountCharacteristic("0a3d3fd8-2f1c-46fd-bf46-eaef2fda91e6", BLERead);

volatile bool doSampling = true;
volatile int sendBuffer = NO_BUFFER;
int samples[BUFFERS][CHANNELS][SAMPLES_PER_NOTIFY] = {0};
int currentSample = 0;
int currentBuffer = 0;
unsigned char tick = 1;
char bleString[BLE_CHARACTERISTIC_SIZE] = {0};
bool bleConnected = false;

// Metrics
#if SEND_METRICS == true
volatile unsigned long minSampleDelay, maxSampleDelay, lastSampleMicroSeconds = 0;
#endif

void setup() {
  //Serial.begin(115200);
  analogReadResolution(12);
  pinMode(LED_BUILTIN, OUTPUT);
  pinMode(LEDR, OUTPUT);
  pinMode(LEDG, OUTPUT);
  pinMode(LEDB, OUTPUT);
  pinMode(JUMPER_PIN_TO_DISABLE_IMU, INPUT_PULLUP);  // HIGH by default. IMU disabled on LOW.
  digitalWrite(LEDR, HIGH); // The LED is LOW-activated, let's turn it off.
  digitalWrite(LEDG, HIGH); // The LED is LOW-activated, let's turn it off.
  //digitalWrite(LEDB, HIGH); // The LED is LOW-activated, let's turn it off.
  analogWrite(LEDB, 255); // The LED is LOW-activated, let's turn it off.
  if (!BLE.begin()) {
    digitalWrite(LEDR, LOW); // Turn on red LED
    while (1);
  }
  #if USE_INTERRUPT_TIMER == true
  if (!samplingTimer.attachInterruptInterval(SAMPLE_INTERVAL_uS, samplingTimerHandler)) {
    digitalWrite(LEDR, LOW); // Turn on red LED
    digitalWrite(LEDG, LOW); // Turn on green LED
    while (1);
  }
  samplingTimer.stopTimer();
  #endif
  if (!IMU.begin()) {
    digitalWrite(LEDR, LOW); // Turn on red LED
    digitalWrite(LEDG, LOW); // Turn on green LED
    while (1);
  }
  BLE.setLocalName("PsyLink");
  BLE.setAdvertisedService(sensorService);
  sensorService.addCharacteristic(sensorCharacteristic);
  sensorService.addCharacteristic(channelCountCharacteristic);
  BLE.addService(sensorService);
  BLE.setEventHandler(BLEConnected, bleConnectHandler);
  BLE.setEventHandler(BLEDisconnected, bleDisconnectHandler);
  //sensorCharacteristic.setEventHandler(BLERead, sensorCharacteristicRead);
  sensorCharacteristic.writeValue("0");
  channelCountCharacteristic.writeValue(CHANNELS);
  BLE.setConnectionInterval(BLE_CONNECTION_INTERVAL_MIN, BLE_CONNECTION_INTERVAL_MAX);
  BLE.advertise();
  for (int i = 0; i < BLE_CHARACTERISTIC_SIZE; i++) { bleString[i] = i+1; }
}

unsigned long nextFrame = 0;
void loop() {
  #if USE_INTERRUPT_TIMER == true
  if (doSampling) {
  #else
  if (micros() >= nextFrame) {
  #endif
    readSamples();
    #if USE_INTERRUPT_TIMER == false
    nextFrame = micros() + 1000;
    #endif
  }
  if (sendBuffer != NO_BUFFER) {
    updateSensorCharacteristic();
  }
  BLE.poll();
}

void sensorCharacteristicRead(BLEDevice central, BLECharacteristic characteristic) {
  updateSensorCharacteristic();
}

#if USE_INTERRUPT_TIMER == true
void samplingTimerHandler() {
  doSampling = true;
}
#endif

void readSamples() {
  #if USE_INTERRUPT_TIMER == false
  doSampling = false;
  #endif

  for (int channel = 0; channel < CHANNELS; channel++)
    samples[currentBuffer][channel][currentSample] = analogRead(channel);
  currentSample++;
  if (currentSample >= SAMPLES_PER_NOTIFY) {
    sendBuffer = currentBuffer;
    currentBuffer = (currentBuffer + 1) % BUFFERS;
    currentSample = 0;
    tick++;
    if (tick == 0) {
      tick++;
    }
  }

  #if SEND_METRICS == true
  unsigned long int currentMicroSeconds = micros();
  unsigned long int sampleDelay = currentMicroSeconds - lastSampleMicroSeconds;
  lastSampleMicroSeconds = currentMicroSeconds;
  if (maxSampleDelay < sampleDelay)
    maxSampleDelay = sampleDelay;
  if (minSampleDelay > sampleDelay)
    minSampleDelay = sampleDelay;
  #endif
}

void updateSensorCharacteristic() {
  if (sendBuffer == NO_BUFFER || !bleConnected) return;
  int pos = 0;
  char currentChar;
  float x, y, z;

  // Read configuration pins
  bool enableIMU = digitalRead(JUMPER_PIN_TO_DISABLE_IMU);

  // Metadata
  bleString[pos++] = tick;
  #if SEND_METRICS == true
  bleString[pos++] = (COMPRESS_DELAY(minSampleDelay) << 4) | COMPRESS_DELAY(maxSampleDelay);
  #else
  bleString[pos++] = 0xFF;
  #endif
  if (enableIMU == HIGH && IMU.gyroscopeAvailable()) {
    IMU.readGyroscope(x, y, z);
    bleString[pos++] = min(255, max(1, x+127));
    bleString[pos++] = min(255, max(1, y+127));
    bleString[pos++] = min(255, max(1, z+127));
  }
  else {
    bleString[pos++] = 128;
    bleString[pos++] = 128;
    bleString[pos++] = 128;
  }
  if (enableIMU == HIGH && IMU.accelerationAvailable()) {
    IMU.readAcceleration(x, y, z);
    bleString[pos++] = min(255, max(1, 128*x+127));
    bleString[pos++] = min(255, max(1, 128*y+127));
    bleString[pos++] = min(255, max(1, 128*z+127));
  }
  else {
    bleString[pos++] = 128;
    bleString[pos++] = 128;
    bleString[pos++] = 128;
  }

  // Sample data
  for (int sample = 0; sample < SAMPLES_PER_NOTIFY; sample++) {
    for (int channel = 0; channel < CHANNELS; channel++) {
      // Avoid writing 0x00 since that denotes the end of the string
      currentChar = map(samples[sendBuffer][channel][sample], 0, 4096, 1, 255);
      bleString[pos++] = max(1, min(currentChar, 255));
    }
  }

  bleString[pos] = 0;  // End the string with 0x00
  sensorCharacteristic.writeValue(bleString);

  // Reset values
  sendBuffer = NO_BUFFER;
  #if SEND_METRICS == true
  minSampleDelay = 999999999;
  maxSampleDelay = 0;
  lastSampleMicroSeconds = micros();
  #endif
}

void bleConnectHandler(BLEDevice central) {
  analogWrite(LEDB, 253);
  connectedDevice = central;
  bleConnected = true;
  currentSample = 0;
  currentBuffer = 0;
  #if SEND_METRICS == true
  minSampleDelay = 999999999;
  maxSampleDelay = 0;
  #endif
  tick = 1;
  sendBuffer = NO_BUFFER;
  for (int buf = 0; buf < BUFFERS; buf++)
    for (int channel = 0; channel < CHANNELS; channel++)
      for (int sample = 0; sample < SAMPLES_PER_NOTIFY; sample++)
        samples[buf][channel][sample] = 0;
  //samplingTimer.restartTimer();
}

void bleDisconnectHandler(BLEDevice central) {
  //samplingTimer.stopTimer();
  analogWrite(LEDB, 255);
  bleConnected = false;
}

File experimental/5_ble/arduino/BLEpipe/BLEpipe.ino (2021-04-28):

#include <ArduinoBLE.h>
#include "NRF52_MBED_TimerInterrupt.h"

// Configuration
#define SAMPLE_RATE 200
#define BLE_NOTIFY_RATE 35 // DO NOT exceed BLE characteristic length limit of 512 (255?) bytes
#define CHANNELS 8
#define BUFFERS 2

// Constants
const int SAMPLE_INTERVAL_uS = 1000000 / SAMPLE_RATE;
const int BLE_NOTIFY_INTERVAL_MS = 1000 / BLE_NOTIFY_RATE;
const int SAMPLES_PER_INTERVAL = SAMPLE_RATE / BLE_NOTIFY_RATE;
const int BLE_CHARACTERISTIC_SIZE = CHANNELS * SAMPLES_PER_INTERVAL;
const int NO_BUFFER = -1;

NRF52_MBED_Timer samplingTimer(NRF_TIMER_3);
BLEDevice connectedDevice;
BLEService sensorService("0a3d3fd8-2f1c-46fd-bf46-eaef2fda91e4");
BLEStringCharacteristic sensorCharacteristic("0a3d3fd8-2f1c-46fd-bf46-eaef2fda91e5",
    BLERead | BLENotify, BLE_CHARACTERISTIC_SIZE);

volatile bool doSampling = true;
volatile int sendBuffer = NO_BUFFER;
int samples[BUFFERS][CHANNELS][SAMPLES_PER_INTERVAL] = {0};
int currentSample = 0;
int currentBuffer = 0;
char bleString[BLE_CHARACTERISTIC_SIZE] = {0};
int fps = 0;
unsigned int nextframe = 0;

volatile int tick1, tick2, tick3;

void setup() {
  Serial.begin(115200);
  analogReadResolution(12);
  pinMode(LED_BUILTIN, OUTPUT);
  pinMode(LEDR, OUTPUT);
  pinMode(LEDG, OUTPUT);
  pinMode(LEDB, OUTPUT);
  digitalWrite(LEDR, HIGH); // The LED is LOW-activated, let's turn it off.
  digitalWrite(LEDG, HIGH); // The LED is LOW-activated, let's turn it off.  
  digitalWrite(LEDB, HIGH); // The LED is LOW-activated, let's turn it off.  
  if (!BLE.begin()) {
    digitalWrite(LEDR, LOW); // Turn on red LED
    while (1);
  }
  if (!samplingTimer.attachInterruptInterval(SAMPLE_INTERVAL_uS, samplingTimerHandler)) {
    digitalWrite(LEDR, LOW); // Turn on red LED
    digitalWrite(LEDG, LOW); // Turn on green LED
    while (1);
  }
  samplingTimer.stopTimer();
  BLE.setLocalName("Myocular");
  BLE.setAdvertisedService(sensorService);
  sensorService.addCharacteristic(sensorCharacteristic);
  BLE.addService(sensorService);
  BLE.setEventHandler(BLEConnected, bleConnectHandler);
  BLE.setEventHandler(BLEDisconnected, bleDisconnectHandler);
  sensorCharacteristic.writeValue("0");
  BLE.advertise();
  for (int i = 0; i < BLE_CHARACTERISTIC_SIZE; i++) { bleString[i] = i+1; }
}

void loop() {
  if (doSampling) {
    readSamples();
    if (sendBuffer != NO_BUFFER && connectedDevice && connectedDevice.connected()) {
      tick1 = millis();
      updateSensorCharacteristic();
      tick2 = millis() - tick1;
    }
  }
  //Serial.println(samples[currentBuffer][1][currentSample]);

  tick1 = millis();
  BLE.poll();
  tick3 = millis() - tick1;

  //Serial.print(tick2);
  //Serial.print(" ");
  //Serial.println(tick3);
}

void samplingTimerHandler() {
  doSampling = true;
}

void readSamples() {
  doSampling = false;
  for (int channel = 0; channel < 0; channel++)
    samples[currentBuffer][channel][currentSample] = analogRead(channel);
  currentSample++;
  if (currentSample >= SAMPLES_PER_INTERVAL) {
    sendBuffer = currentBuffer;
    currentBuffer = (currentBuffer + 1) % BUFFERS;
    currentSample = 0;
  }
  fps++;
  if (millis() > nextframe) {
    Serial.println(fps);
    fps = 0;
    nextframe += 1000;
  }
}

void updateSensorCharacteristic() {
  sensorCharacteristic.writeValue(bleString); return;
  if (sendBuffer == NO_BUFFER) return;
  int pos = 0;
  for (int sample = 0; sample < SAMPLES_PER_INTERVAL; sample++) {
    for (int channel = 0; channel < CHANNELS; channel++) {
      bleString[pos++] = map(samples[sendBuffer][channel][sample], 0, 4095, 0, 254) + 1;
    }
  }
  bleString[pos] = 0;
  sensorCharacteristic.writeValue(bleString);
  sendBuffer = NO_BUFFER;
}

void bleConnectHandler(BLEDevice central) {
  digitalWrite(LEDB, LOW);
  connectedDevice = central;
  currentSample = 0;
  currentBuffer = 0;
  sendBuffer = NO_BUFFER;
  for (int buf = 0; buf < BUFFERS; buf++)
    for (int channel = 0; channel < CHANNELS; channel++)
      for (int sample = 0; sample < SAMPLES_PER_INTERVAL; sample++)
        samples[buf][channel][sample] = 0;
  samplingTimer.restartTimer();
  nextframe = millis() + 1000;
}

void bleDisconnectHandler(BLEDevice central) {
  samplingTimer.stopTimer();
  digitalWrite(LEDB, HIGH);
}

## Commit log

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2021-04-11 fix NN label shape
    [ai.py]
2021-04-12 more tweaks & fixes
    [ai.py, run.py]
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2021-04-12 normalize electrode sensor readings to [0,1]
    I don't know if this is even necessary, but hey, let's add a bunch of
    unnecessary FLOPS to our main loop for elegance purposes. (I may revert
    this later...)
    [DumbPipe.ino]
2021-04-12 fixed late night bug that ruined everything^TM
    [ai.py]
2021-04-12 fixed reuse of training data in validation on multiple trainings
    [run.py]
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2021-04-15 threaded serial reads, implemented fixed sampling rate & prediction rate
    [ai.py, lib.py, run.py]
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2021-04-15 added DumbPipeFast that outputs samples at a fixed rate
    [DumbPipeFast.ino, samplespersecond.py]
2021-04-25 add schematic of design #4
    [myocular0.4.sch]
2021-04-25 added schematics for older prototypes
    [myocular0.1.sch, myocular0.2.sch, myocular0.3.sch]
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2021-04-28 added schematic for circuit 0.5
    [myocular0.5.sch]
2021-04-28 fixed typo in schematic 0.5
    [myocular0.5.sch]
2021-04-29 fixed bug in schematic
    [myocular0.5.sch]
2021-04-30 added 0.5.1 schematic & pcb
    [myocular0.5.1.kicad_pcb, myocular0.5.1.sch]
2021-04-30 swap resistor for capacitor...
    [myocular0.5.1.kicad_pcb]
2021-05-01 add newest pcb layout
    [myocular0.5.1d.kicad_pcb]
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2021-05-04 add gerber files for PCB order #1
    [myocular0.5.1d-B_Cu.gbl, myocular0.5.1d-B_Mask.gbs, myocular0.5.1d-Edge_Cuts.gm1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]
2021-05-04 add buggy PCBs for documentation purposes
    [myocular0.5.1a.kicad_pcb, myocular0.5.1b.kicad_pcb, myocular0.5.1c.kicad_pcb]
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2021-05-07 fix missing training_data.label_order after model load
    [ai.py]
2021-05-07 implement resetting AI, and build training data only when needed
    [ai.py]
2021-05-07 fix crash when loading recordings and recording again
    [ai.py]
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2021-05-17 fix order of magnitude of sample intervals
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2021-05-18 reverse how samples are attached to SignalBuffer
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2021-06-04 add c8 + bp2 + Keystone 82 footprint
    [circuit8.kicad_pcb, circuit8.sch]
2021-06-04 updated c8 cirucit diagram
    [circuit8.sch]
2021-06-15 add circuit9 schematic + pcb
    [circuit9.kicad_pcb, circuit9.sch]
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2021-06-15 add orders of june 2021
    [circuit8-B_Cu.gbr, circuit8-B_Mask.gbr, circuit8-B_Paste.gbr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]
2021-06-15 rename old order folder
    [myocular0.5.1d-B_Cu.gbl, myocular0.5.1d-B_Mask.gbs, myocular0.5.1d-Edge_Cuts.gm1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]
2021-06-15 update circuits & order
    [circuit9-B_Cu.gbr, circuit9-B_Mask.gbr, circuit9-B_Paste.gbr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]
2021-06-15 minor adjustment in circuit9
    [circuit9.sch]
2021-06-17 fix bugs in circuit9 schematic + pcb
    [circuit9.kicad_pcb, circuit9.sch]
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2021-07-07 add schematics/bp3.1 (WIP), breaking the naming scheme ;D
    [bp3.1.kicad_pcb]
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2021-07-25 don't send IMU data when pin D2 is grounded (Fixes #24)
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2021-09-14 Larger pads on bp3.1 for easier soldering (fixes #8)
    [bp3.1.kicad_pcb]
2021-09-15 updated/finalized bp3.1 (makes room for 1210 package inductance)
    [bp3.1.kicad_pcb]
2021-09-17 started working on quad inst.amp. circuit
    [circuit10.sch]
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2021-09-30 finished circuit10 + board3
    [b3.kicad_pcb, circuit10.sch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]
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2021-09-30 polished b3 some more
    [b3.kicad_pcb, circuit10.sch]
2021-09-30 enlarge rubber band holes
    [b3.kicad_pcb]
2021-09-30 final polishing of b3 before ordering
    [b3.kicad_pcb]
2021-09-30 last minute change adding electrode test pins to b3
    [b3.kicad_pcb, circuit10.sch]
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2021-10-06 fix missing connections at EX4 and EX8
    [b3.kicad_pcb]
2021-12-11 first design of bp4 (but of course I forgot the mounting holes...)
    [bp4.kicad_pcb]
2021-12-11 added circuit 11 and small changes to bp4
    [bp4.kicad_pcb, circuit11.sch]
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2021-12-11 routed bp4, jumpers & labels missing tho
    [bp4.kicad_pcb]
2021-12-11 added screws & solder jumpers to circuit11
    [bp4.kicad_pcb, circuit11.sch]
2021-12-12 finished bp4 (or so it seems)
    [bp4.kicad_pcb]
2021-12-15 better comments in circuit11
    [circuit11.sch]
2021-12-15 final updates on bp4. also added it to schematics/orders/
    [bp4.kicad_pcb]
2021-12-19 move SW1 to the left to make space for larger power switches
    [bp4.kicad_pcb]
2021-12-19 move JP8 away from battery clip to avoid short circuit with ground
    [bp4.kicad_pcb]
2021-12-19 add silkscreen to JP1 pins
    [bp4.kicad_pcb]
2021-12-19 swap horizontal pin headers for vertical pin headers
    [bp4.kicad_pcb, circuit11.sch]
2021-12-19 restore original bp4 and rename the updated one to bp4.1
    [bp4.1.kicad_pcb]
2021-12-19 update model name to bp4.1 on silk screen
    [bp4.1.kicad_pcb]
2021-12-19 fix J1 silkscreen
    [bp4.1.kicad_pcb]
2021-12-19 started working on revising b3, added b3.1
    [b3.1.kicad_pcb]
2021-12-19 add "(voltage setter)" label to R2 in bp4.1
    [bp4.1.kicad_pcb]
2021-12-19 move labels for all thru-hole components of bp4.1 to backside
    [bp4.1.kicad_pcb]
2021-12-19 enlarge contact pads for electrode screws for b3.1
    [b3.1.kicad_pcb]
2022-01-06 break ground loop on back side of b3.1
    [b3.1.kicad_pcb]
2022-01-06 update bp4.1 to include external power supply + power LED
    [bp4.1.kicad_pcb, circuit12.sch]
2022-01-06 On b3.1, route EX1-C1 past EL1, to allow cutting C1-EL1 if needed
    same for EX2-C2 and EL2, and all the other electrodes
    You may want to use external electrodes with the board, but you
    currently can neither disable the built-in EL1-EL8 electrodes, nor can
    you remove them since they're used for physical support. Ideally there
    should be a jumper, but there's little space. So for the time being, if
    you really want to disconnect the electrodes, you can now cut the copper
    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
    [b3.1.kicad_pcb]
2022-01-07 On b3.1, add jumpers for electrodes, so u can quickly switch to external ones
    [b3.1.kicad_pcb, circuit10.1.sch]
2022-01-07 polish bp4.1 and circuit11.1
    [bp4.1.kicad_pcb, circuit11.1.sch]
2022-01-07 add recent PCB order
    [b3.1.kicad_pcb, bp4.1.kicad_pcb]
2022-01-07 remove accidentally added WIP file circuit11.1.sch
    [circuit11.1.sch]
2022-01-26 add bp3.2 (moved EX* pins, added logo)
    [bp3.2.kicad_pcb]
2022-01-26 draw rectangles around gain resistors
    [bp3.2.kicad_pcb]
2022-01-26 hide U* labels under chips. add "signal*" labels.
    [bp3.2.kicad_pcb]
2022-01-26 add circuit 10.2 (bridged sldr jumpers, 100Ohm gain res.)
    [circuit10.2.sch]
2022-01-26 grow INA128's solder pads for easier assembly
    [bp3.2.kicad_pcb]
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2022-01-26 add silkscreen on backside for signals and electrode polarity
    [bp3.2.kicad_pcb]
2022-01-26 upgrade from c10.1 to c10.2 (bridge solder jumpers by default)
    [bp3.2.kicad_pcb]
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2022-01-26 add c12.1 and bp4.2, containing simplifications/optimizations
    [bp4.2.kicad_pcb, circuit12.1.sch]
2022-01-26 minor tweaks to bp3.2
    [bp3.2.kicad_pcb]
2022-01-26 fix name of schematic (bp3.2 -> b3.2)
    Those names are starting to get confusing...
    [b3.2.kicad_pcb]
2022-02-01 double resistance on R10, add comment
    [circuit10.2.sch]
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2022-02-01 add 2022-01-26 PCB order
    [b3.2.kicad_pcb, bp4.2.kicad_pcb]
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2022-02-23 Remove focus in GUI when pressing ESC (fixes #5)
2022-04-26 Add new Electrode Module design from AntonX
    [PsyLinkMCP.kicad_pcb, PsyLinkMCP.sch]
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2023-04-10 move loose kicad files to archive/kicad/
    [PsyLinkMCP.kicad_pcb, PsyLinkMCP.kicad_sch, PsyLinkMCP.sch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]
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2023-04-10 removed unneeded "bug fix" of lowering gain by half on 2nd output
    [PsyLinkMCP.kicad_sch]
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2023-06-16 fix gain resistor in circuit c10.3 (now c10.4)
    [electrode_module3.3.kicad_sch]
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

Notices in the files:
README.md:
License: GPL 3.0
